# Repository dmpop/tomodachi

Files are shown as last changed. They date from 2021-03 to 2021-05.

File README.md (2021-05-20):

# Tomodachi

Tomodachi is a hardware add-on that extends functionality of a Raspberry Pi-compatible single-board computer. The board features an 128x64 LCD screen, two LEDs, and two push buttons. Thanks to its simplicity and versatility, the board can be put to a wide variety of practical and creative uses.

Tomodachi was originally designed as a companion to [Little Backup Box](https://github.com/dmpop/little-backup-box). However, the accompanying shell scripts transform the Raspberry Pi into a self-contained appliance that can run custom commands via a programmable button-driven on-screen menu.



## Author

[Dmitri Popov](https://www.tokyoma.de/)

## License

The [GNU General Public License version 3](http://www.gnu.org/licenses/gpl-3.0.en.html)

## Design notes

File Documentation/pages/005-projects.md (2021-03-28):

# Tomodachi projects

Since Tomodachi makes it possible to run practically any command and script on the Raspberry Pi, what you can use the board for is limited only by your imagination and programming skills. Here are a few ideas you can use as starting points.

## Internet radio streaming

1. Install MPlayer on the Raspberry Pi using the `sudo apt install mplayer` command.
2. Create the _playlists_ folder in the _/home/pi_ directory.
3. Use the [Community Radio Browser](https://www.radio-browser.info/) to find radio stations you like, and download their PLS files to the _/home/pi/playlists_ directory.
4. Open the _tomodachi/scripts/commands.csv_ file for editing and add the following commands (replace examples with the actual names of radio stations and correct paths to their respective playlist files):

```
Stop radio, eval sudo killall mplayer &>/dev/null & disown;
Station 1, eval mplayer -playlist /home/pi/playlists/station1.pls &>/dev/null & disown;
Station 2, eval mplayer -playlist /home/pi/playlists/station2.pls &>/dev/null & disown;
```

5. Save the changes and reboot the Raspberry Pi.
6. Use the **SELECT** button to choose the desired station and press **RUN** to stream it.

Note that if you want to switch to a different station, you need to run the **Stop radio** command first.

## Camera remote control

If your camera is supported by [gPhoto2](http://gphoto.org/), you can turn the Raspberry Pi and Tomodachi combo into a tethered camera controller.

1. Install gPhoto2 on the Raspberry Pi using the `sudo apt install gphoto2` command.
2. Open the _tomodachi/scripts/commands.csv_ file for editing and add the following commands:

```
Capture, gphoto2 --capture-image-and-download --filename %Y%m%d-%H%M%S-%03n.%C
Get all files, --get-all-files --skip-existing --filename %Y%m%d-%H%M%S-%03n.%C
```

The first command takes a photo, while the second one transfers all files from the camera to the Raspberry Pi.

3. Save the changes and reboot the Raspberry Pi.
4. Connect your camera to the Raspberry Pi. Switch the camera on and enable the remote control mode, if necessary.
5. Use the **SELECT** button to choose the desired command and press **RUN** to stream it.

## Fetch weather conditions

In addition to specifying direct commands, it's also possible to call external shell scripts from the _commands.csv_ file. This allows you to define complex multi-command actions. For example, you can create a script that displays the weather conditions in a specific city and call the script from the command file.

1. On the Raspberry Pi, run the `nano weather.sh` command and paste the following code into the blank text file (replace _Tokyo_ with the desired city):

```bash
#!/usr/bin/env bash
city="Tokyo"
t=$(curl wttr.in/$city?format="%t")
w=$(curl wttr.in/$city?format="%w")
p=$(curl wttr.in/$city?format="%p")
sudo oled r
sudo oled +a "= $city ="
sudo oled +b "Temp: $t"
sudo oled +c "Wind: $w"
sudo oled +d "Precip: $p"
sudo oled s
```

The script uses the _curl_ tool to fetch weather conditions via the [wttr.in](https://wttr.in/) service, parses the obtained data, and displays it on the screen.

2. Save the file in the _/home/pi_ directory and make the script executable using the `chmod +x weather.sh` command.
3. Open the _tomodachi/scripts/commands.csv_ file for editing and add the following command to it:

    Weather, sudo /home/pi/weather.sh

4. Save the changes and reboot the Raspberry Pi.
5. Use the **SELECT** button to choose the **Weather** command and press **RUN** to run it.

## Show storage usage

You can use Tomodachi to display storage usage stats.

1. On the Raspberry Pi, run the `nano usage.sh` command and paste the following code into the blank text file:

```bash
#!/usr/bin/env bash
limit="75"
part="root"
used=$(df -h | grep $part | awk '{ print $3 }')
used_int=$(df -h | grep $part | awk '{ print $5 }' | cut -d'%' -f1)
avail=$(df -h | grep $part | awk '{ print $4 }')
echo $avail
percent=$(df -h | grep $part | awk '{ print $5 }')
sudo oled r
sudo oled +a "= $part ="
sudo oled +b "Used: $used"
sudo oled +c "Avail: $avail"
sudo oled +d "Percent: $percent"
sudo oled s
if [ $used_int -gt $limit ]; then
  sudo sh -c "echo timer > /sys/class/leds/led0/trigger"
  sudo sh -c "echo 1000 > /sys/class/leds/led0/delay_on"
fi
```

The `limit` variable determines when to trigger the ACT LED, which indicates that the storage capacity is nearing its limit. By default, it's set to 75% of used storage space, but you can adjust it, if necessary. You can also specify a different storage partition by modifying the value of the `part` variable.

2. Save the file in the _/home/pi_ directory and make the script executable using the `chmod +x usage.sh` command.
3. Open the _tomodachi/scripts/commands.csv_ file for editing and add the following command to it:

    Storage usage, sudo /home/pi/usage.sh

4. Save the changes and reboot the Raspberry Pi.
5. Use the **SELECT** button to choose the **Storage usage** command and press **RUN** to run it.

## Show stats

You can use Tomodachi to display hardware stats.

1. On the Raspberry Pi, run the `nano stats.sh` command and paste the following code into the blank text file:

```bash
#!/usr/bin/env bash
temp=$(expr $(cat /sys/class/thermal/thermal_zone*/temp) / 1000)
mem=$(printf "%0.2f\n" $(free | grep Mem | awk '{print $3/$2 * 100.0}'))
cpu=$(vmstat | tail -1 | awk '{print $15}')
sudo oled r
sudo oled +a "==== STATS ===="
sudo oled +b "- Tem: "$temp"C"
sudo oled +c "- Mem: "$mem"%"
sudo oled +d "- CPU: "$cpu"%"
sudo oled s
```

2. Save the file in the _/home/pi_ directory and make the script executable using the `chmod +x stats.sh` command.
3. Open the _tomodachi/scripts/commands.csv_ file for editing and add the following command to it:

    Storage usage, sudo /home/pi/stats.sh

4. Save the changes and reboot the Raspberry Pi.
5. Use the **SELECT** button to choose the **Stats** command and press **RUN** to run it.

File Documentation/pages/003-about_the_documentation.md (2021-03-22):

# About this documentation

This documentation provides instructions on how to build a Tomodachi board as well as install and configure the required software. The documentation also describes several Tomodoachi-based projects.

# Prerequisites

You need a Raspberry Pi Model 3 or 4 and a bootable microSD card with the latest version of Raspberry Pi OS Lite. Besides basic soldering skills, building your own Tomodachi device requires basic Linux knowledge:

- Establishing an SSH connection
- Editing files
- Running shell scripts and executing basic commands from the command line
- Understanding how Linux handles external devices

It also helps to be familiar with Raspberry Pi and single-board computers in general.

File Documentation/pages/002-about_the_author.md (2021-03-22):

# About the author



Dmitri Popov has been writing exclusively about Linux and open source software for many years, and his articles have appeared in Danish, British, US, German, and Russian magazines and websites. You can find more about his work on his [Tōkyō Made](https://www.tokyoma.de) website.

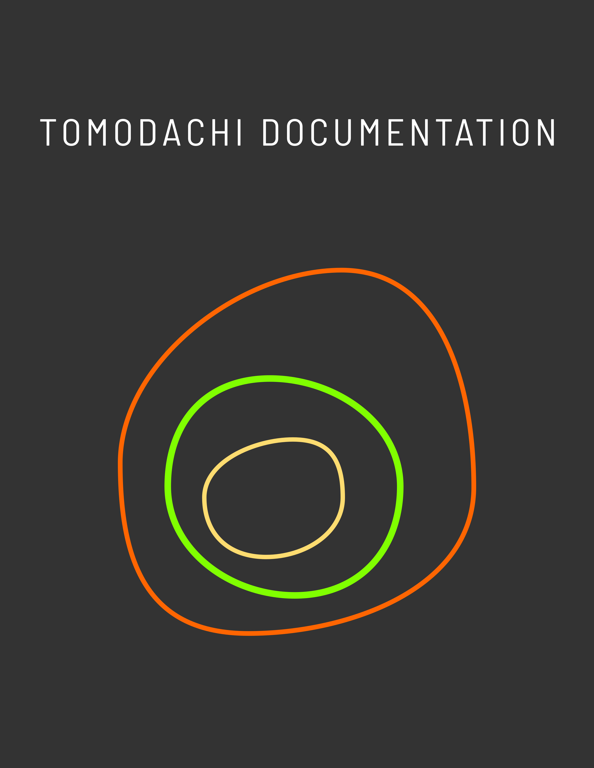
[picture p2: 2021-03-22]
Documentation/bookcover.jpg

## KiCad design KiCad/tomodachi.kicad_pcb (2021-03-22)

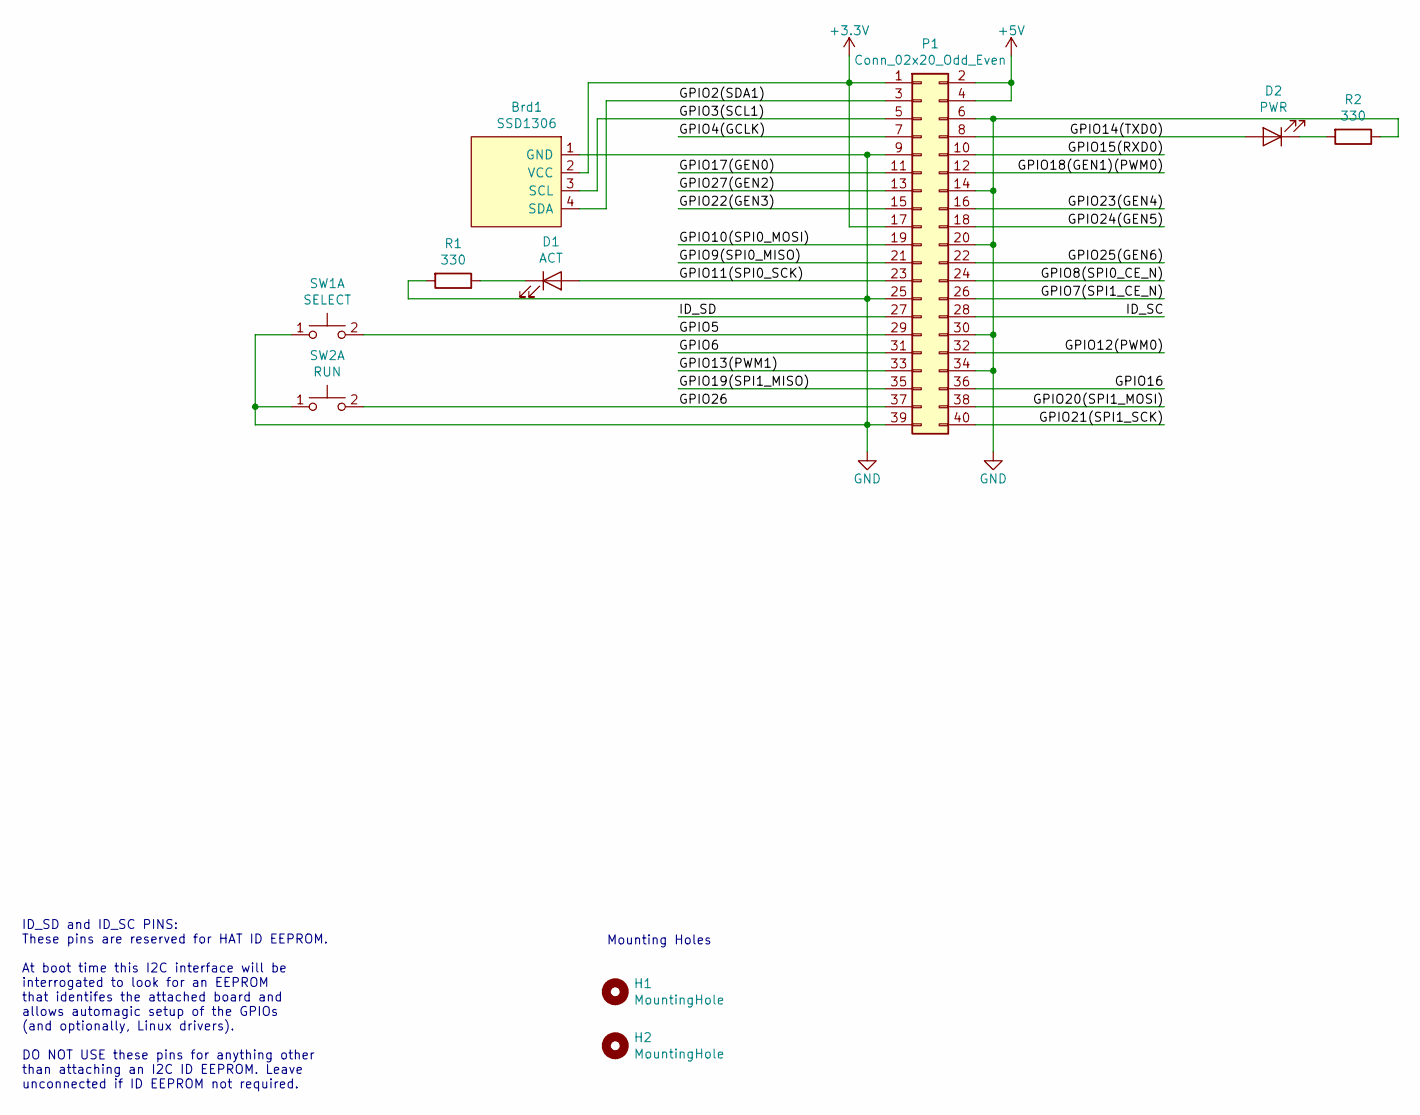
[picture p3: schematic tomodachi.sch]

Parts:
Brd1: SSD1306; 128x64OLED
D1: ACT; LED_D5.0mm
D2: PWR; LED_D5.0mm
H1, H2: MountingHole; MountingHole_2.5mm
P1: Conn_02x20_Odd_Even; PinSocket_2x20_P2.54mm_Vertical
R1, R2: 330; R_Axial_DIN0204_L3.6mm_D1.6mm_P7.62mm_Horizontal
SW1: SELECT; SW_PUSH_6mm_H4.3mm
SW2: RUN; SW_PUSH_6mm_H4.3mm

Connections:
+3V3: Brd1.2 (VCC), P1.1, P1.17
+5V: P1.2, P1.4
/GPIO2(SDA1): Brd1.4 (SDA), P1.3
/GPIO3(SCL1): Brd1.3 (SCL), P1.5
/GPIO4(GCLK): P1.7
/GPIO5: P1.29, SW1.2 (D)
/GPIO6: P1.31
/GPIO7(SPI1_CE_N): P1.26
/GPIO8(SPI0_CE_N): P1.24
/GPIO9(SPI0_MISO): P1.21
/GPIO10(SPI0_MOSI): P1.19
/GPIO11(SPI0_SCK): D1.2 (A), P1.23
/GPIO12(PWM0): P1.32
/GPIO13(PWM1): P1.33
/GPIO14(TXD0): D2.2 (A), P1.8
/GPIO15(RXD0): P1.10
/GPIO16: P1.36
/GPIO17(GEN0): P1.11
/GPIO18(GEN1)(PWM0): P1.12
/GPIO19(SPI1_MISO): P1.35
/GPIO20(SPI1_MOSI): P1.38
/GPIO21(SPI1_SCK): P1.40
/GPIO22(GEN3): P1.15
/GPIO23(GEN4): P1.16
/GPIO24(GEN5): P1.18
/GPIO25(GEN6): P1.22
/GPIO26: P1.37, SW2.2 (D)
/GPIO27(GEN2): P1.13
/ID_SC: P1.28
/ID_SD: P1.27
GND: Brd1.1 (GND), P1.6, P1.9, P1.14, P1.20, P1.25, P1.30, P1.34, P1.39, R1.2, R2.1, SW1.1 (C), SW2.1 (C)
unnamed: D1.1 (K), R1.1
unnamed: D2.1 (K), R2.2

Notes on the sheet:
ID_SD and ID_SC PINS: These pins are reserved for HAT ID EEPROM. At boot time this I2C interface will be interrogated to look for an EEPROM that identifes the attached board and allows automagic setup of the GPIOs (and optionally, Linux drivers). DO NOT USE these pins for anything other than attach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
Mounting Holes

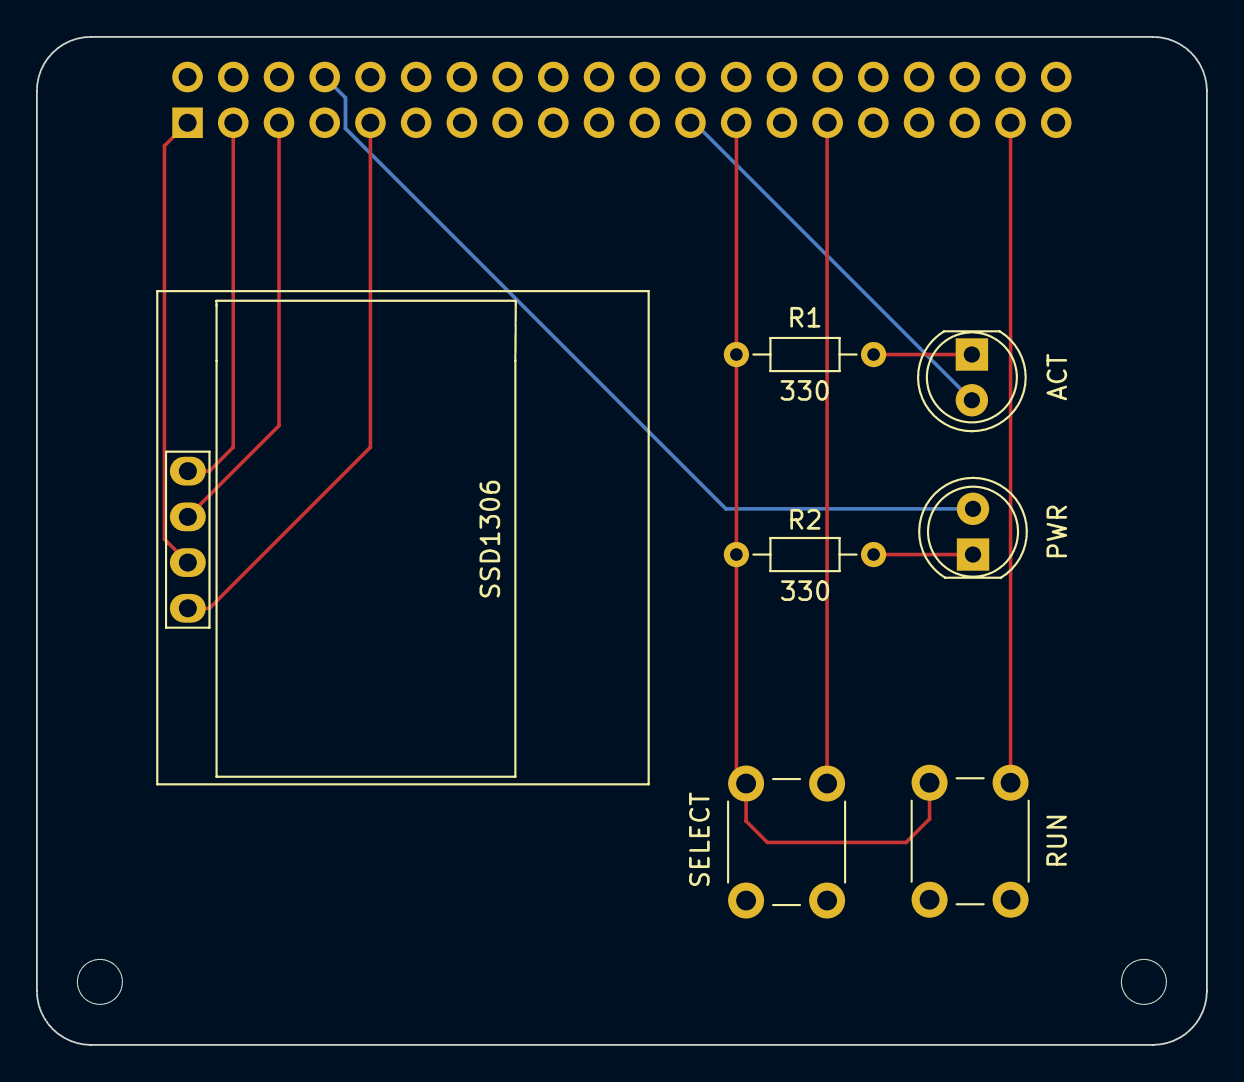
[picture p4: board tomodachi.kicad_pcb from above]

Board: 2 copper layers, 65.0 x 56.0 mm, 10 parts (1 on the bottom side), 11 nets.

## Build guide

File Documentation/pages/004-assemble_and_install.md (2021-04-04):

# Introduction

Tomodachi is a hardware add-on that extends the functionality of a Raspberry Pi-compatible single-board computer. The board features a 128x64 LCD screen, two LEDs, and two push buttons. Thanks to its simplicity and versatility, the board can be put to a variety of practical and creative uses.

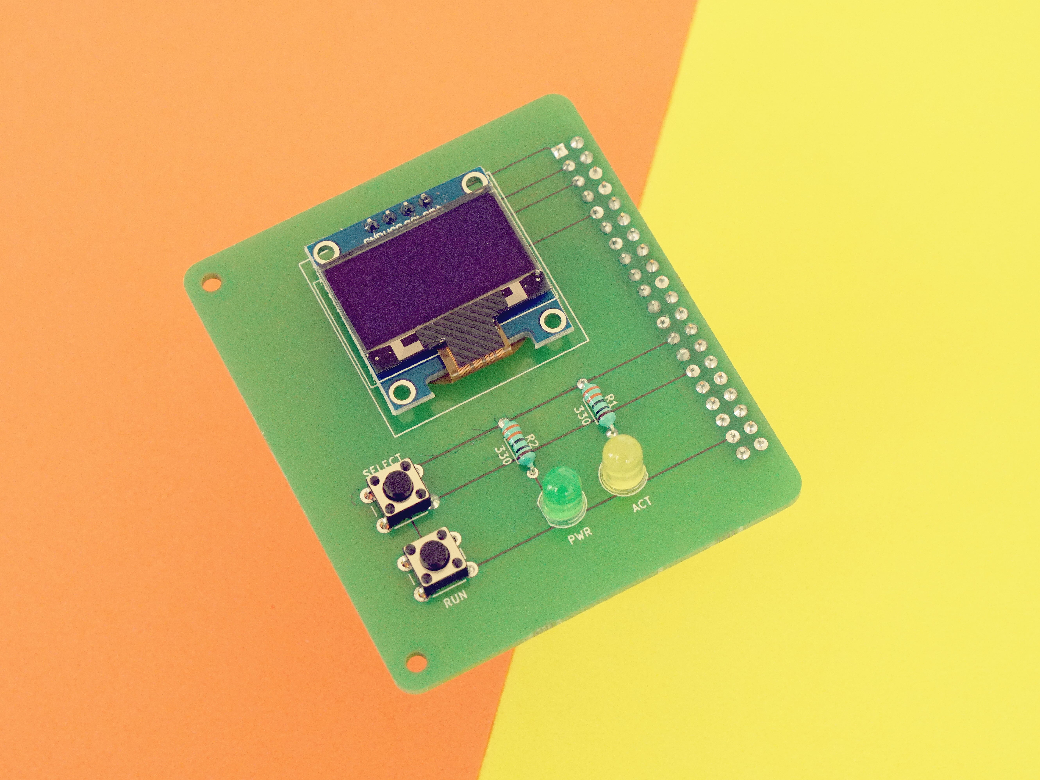
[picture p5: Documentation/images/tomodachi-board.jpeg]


You can order an assembled and ready-to-use Tomodachi via [Gumroad](https://gum.co/tomodachi). Alternatively, you can assemble a board yourself. If you choose the latter option, the first step is to order a PCB. While there are plenty of PCB manufacturers you can choose from, consider using [AISLER](https://aisler.net/). The service uses PCB manufacturing facilities in Germany, so it offers reasonable prices and the fastest delivery within Europe.

Before you order a PCB, clone the Tomodachi Git repository using the `git clone https://github.com/dmpop/tomodachi.git` command. Alternatively, fetch the latest source code from the project's website and unpack the downloaded archive.

To order a PCB from AISLER, upload the _tomodachi.kicad\_pcb_ file in the _tomodachi/KiCad_ folder. To place an order with other manufacturers, zip the _Tomodachi-Gerber_ directory and upload the resulting archive.

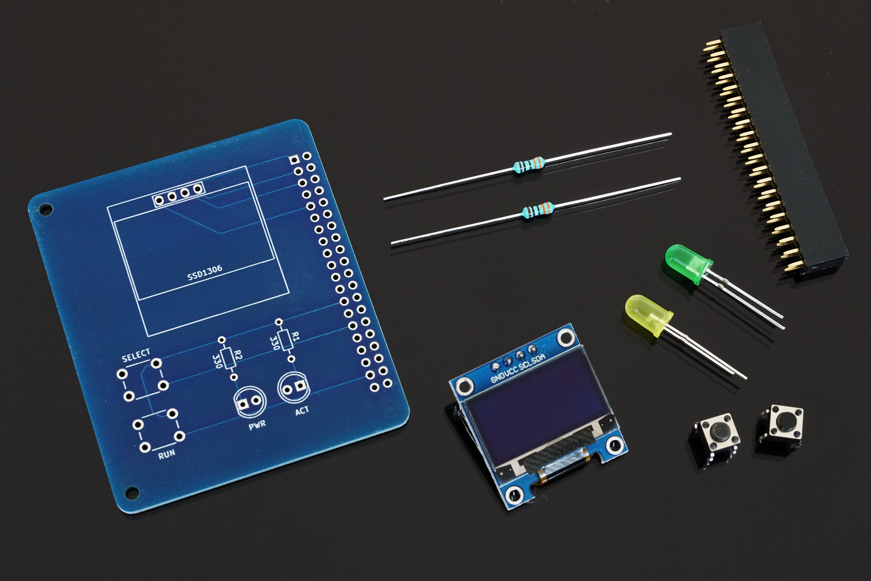
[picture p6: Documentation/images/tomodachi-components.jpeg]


To assemble the board, you need the following:

- Soldering iron
- Solder wire
- 40-pin header compatible with Raspberry Pi GPIO
- 128x64 OLED LCD display
- 2x 330Ω resistors
- 2x 5mm LEDs (preferably different colors)
- 2x 6x6x6mm micro push buttons

# Install software

To enable LEDs on the Tomodachi board, you need to configure the Raspberry Pi OS. To do this, add the following directives to the _config.txt_ file on the _boot_ partition of the storage card with Raspberry Pi OS:

```
enable_uart=1
dtparam=act_led_gpio=11
```

Tomodachi comes with a set of shell scripts that transform it into a programmable menu-driven Raspberry Pi controller. The way it works is simple: add the custom commands you want to run on the Raspberry Pi to the _commands.csv_ text file. Use the **SELECT** button to cycle through the list of commands. Once you've selected the desired command, press the **RUN** button to execute the command on the Raspberry Pi.

To enable this functionality, make sure that the Raspberry Pi is connected to the internet and run the installer script using the following command:

    curl -sSL https://raw.githubusercontent.com/dmpop/tomodachi/main/scripts/install.sh | bash

Once the installation is completed and the Raspberry Pi is rebooted, the LCD display should show the Tomodachi welcome message.

# Basic usage

By default, the supplied _tomodachi/scripts/commands.csv_ file contains two commands: _Show IP_ and _Power off_. Use the **SELECT** button to select the first command, and press the **RUN** button. Assuming that the Raspberry Pi is connected to a network, you should see the machine's IP address. To turn off the Raspberry Pi, use **SELECT** to choose the _Power off_ command and press **RUN**.

## Edit commands

You can populate the _commands.txt_ file with custom commands using the default entries as a starting point. Each entry must follow the `Description, Command` format. The second column can contain an actual command (for example, `touch file.txt`) or point to an existing script (for example, `/home/pi/script.sh`). You can add as many command entries as you need.

To modify the _commands.txt_ file, you can either edit it directly on the Raspberry Pi, or you can do it from another machine via an SSH connection. There is, however, a third option: use a special command in the _commands.txt_ file itself to fetch another version of the file from a remote location. For example, you can create a snippet on [GitLab](https://gitlab.com/) containing the desired commands, and then download it to the Raspberry Pi. This way, you'll be able to edit commands from anywhere.

To configure this feature, create a snippet on GitLab and name it _commands.csv_. Add the desired commands to the snippet, including the following one (replace _2092222_ with the actual ID of the snippet):

    Update commands, wget https://gitlab.com/-/snippets/2092222/raw/master/commands.csv -O /home/pi/tomodachi/scripts/commands.csv

Save the snippet, and note its ID. Now open the _commands.txt_ file on the Raspberry Pi, and add the command above to it too. Save the changes, then use the Tomodachi board to select and run the **Update commands** command to fetch the remote _commands.txt_ file.

It's also possible to configure the Raspberry Pi to fetch the latest command list automatically on every boot. Create a shell script containing the code below:

```bash
ip=$(hostname -I | cut -d' ' -f1)
until [ ! -z "$ip" ]; do
  sleep 1
  wget https://gitlab.com/-/snippets/2092222/raw/master/commands.csv -O /home/pi/tomodachi/scripts/commands.csv
done
```

Save the script under the _/home/pi/update-commands.sh_ name and make the script executable using the `chmod +x update-commands.sh` command. Run the `crontab -e` command and add the following cronjob:

    @reboot sudo /home/pi/update-commands.sh

Save the changes and reboot the Raspberry Pi.

# Update Tomodachi

To update Tomodachi, run the following commands on the Raspberry Pi:

```bash
cd /home/pi/tomodachi
git stash
git pull
git stash pop
```

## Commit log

2021-03-22 Minor tweaks
    [tomodachi.kicad_pcb]
2021-03-23 Update projects
    [commands.csv]
2021-09-13 Enable LEDs
